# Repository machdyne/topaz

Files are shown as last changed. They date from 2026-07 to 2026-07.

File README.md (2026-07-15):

# Topaz Computer

Topaz is a headless computer that uses an ASIC module based on the open-source [KIAN-V RV32 SOC](https://github.com/splinedrive/gf180mcu-kianv-rv32ima-sv32).

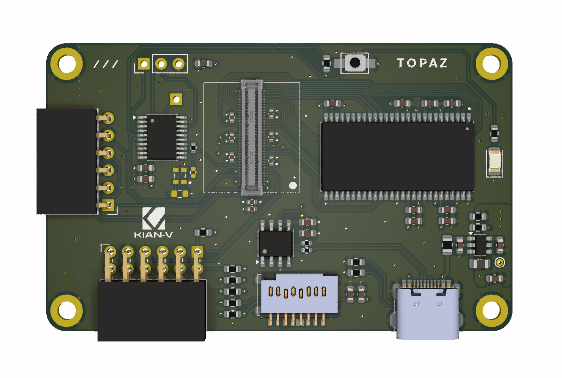
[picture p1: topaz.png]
Topaz Computer


This repo contains schematics, PCB layouts, firmware and documentation.

Find more information on the [Topaz product page](https://machdyne.com/product/topaz-computer/).

## License

The contents of this repo are released under the [Lone Dynamics Open License](LICENSE.md) with the following exceptions:

  * The ch32fun library is MIT licensed.

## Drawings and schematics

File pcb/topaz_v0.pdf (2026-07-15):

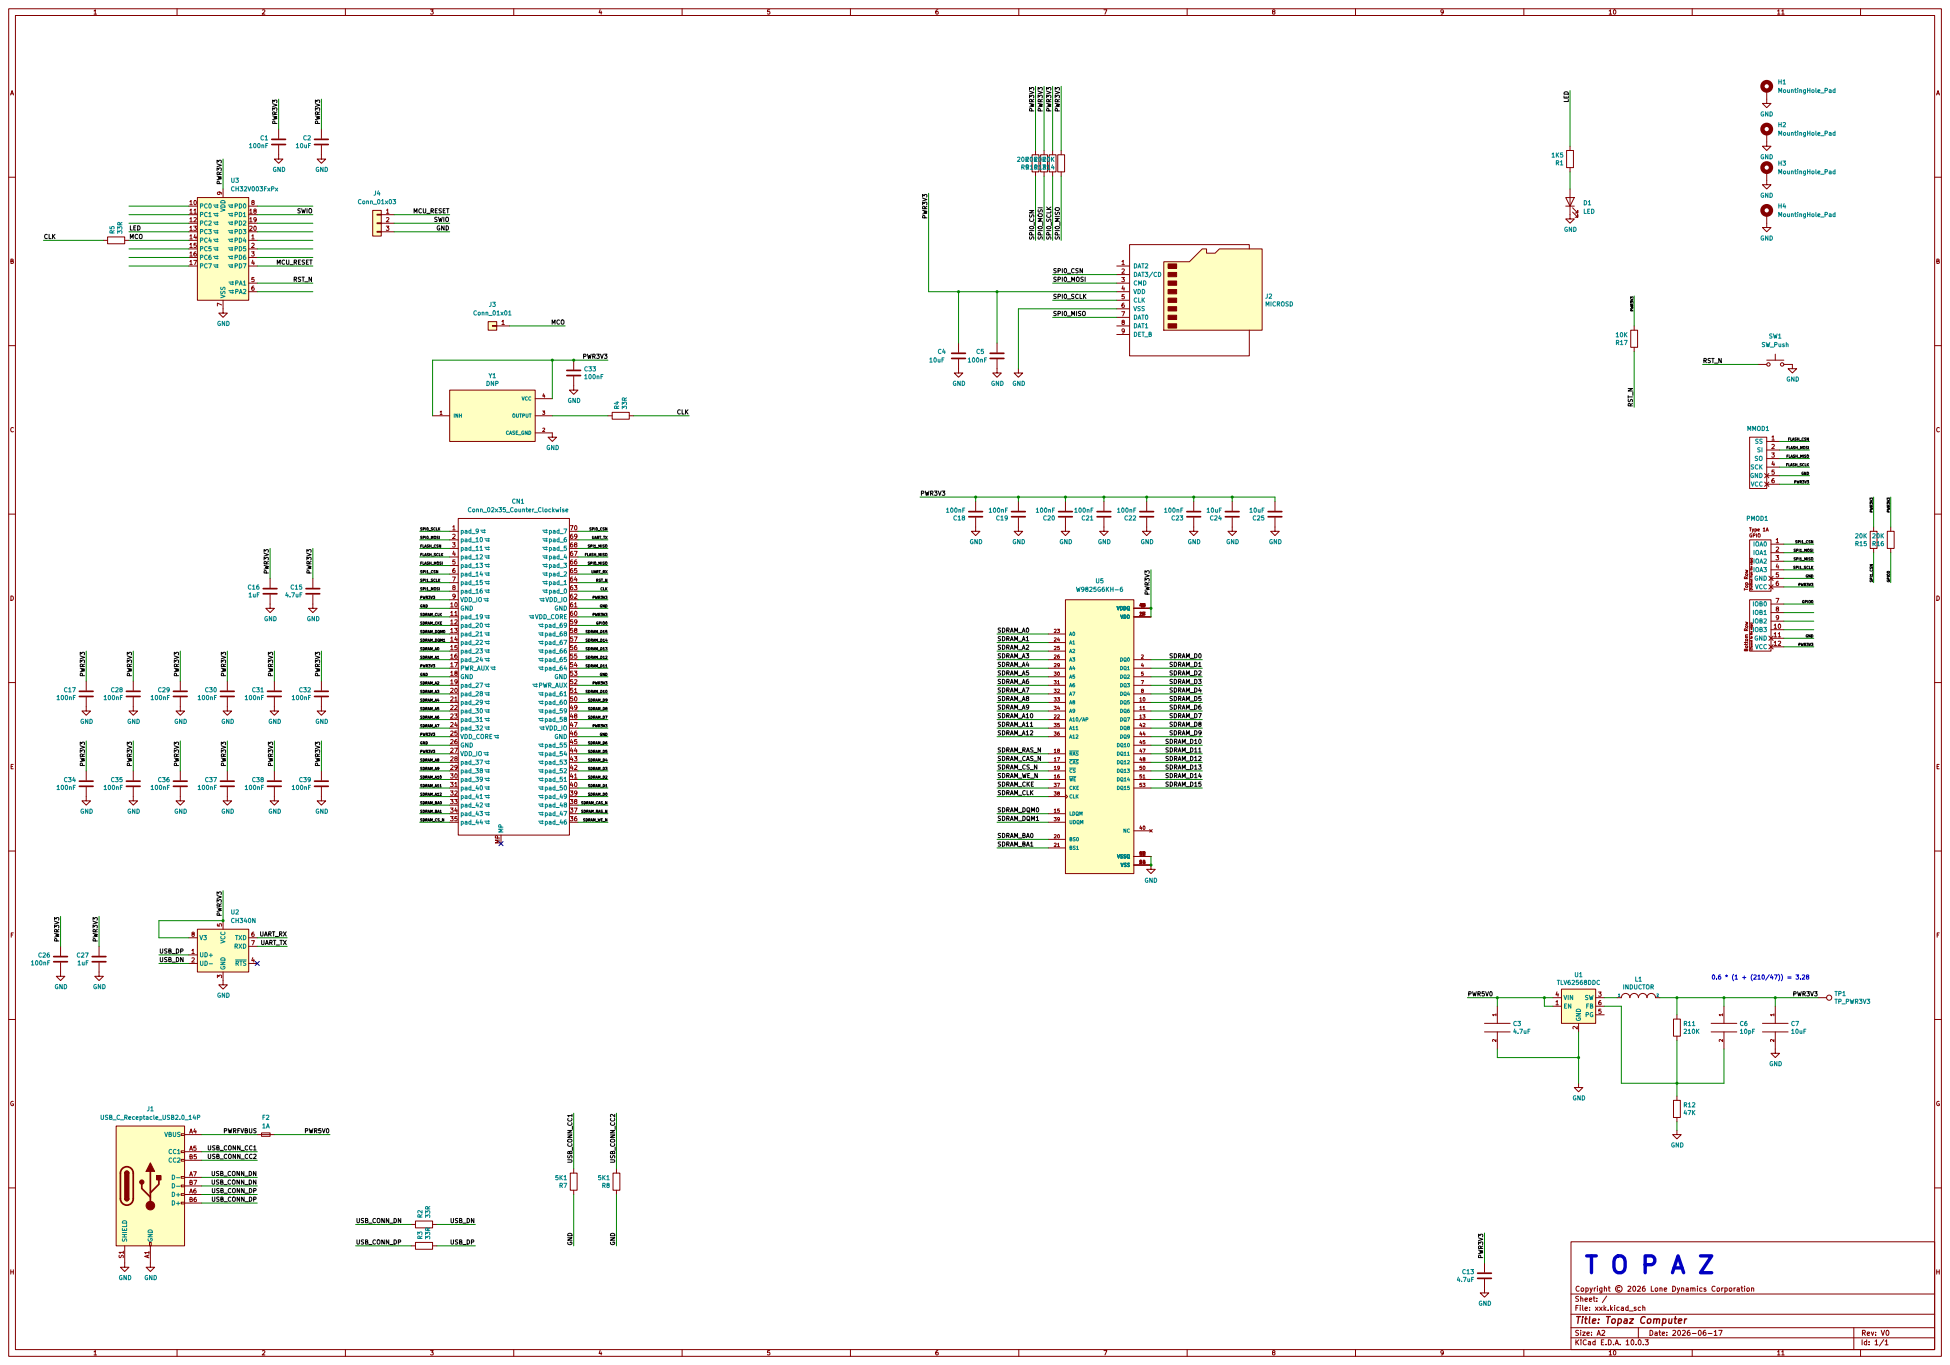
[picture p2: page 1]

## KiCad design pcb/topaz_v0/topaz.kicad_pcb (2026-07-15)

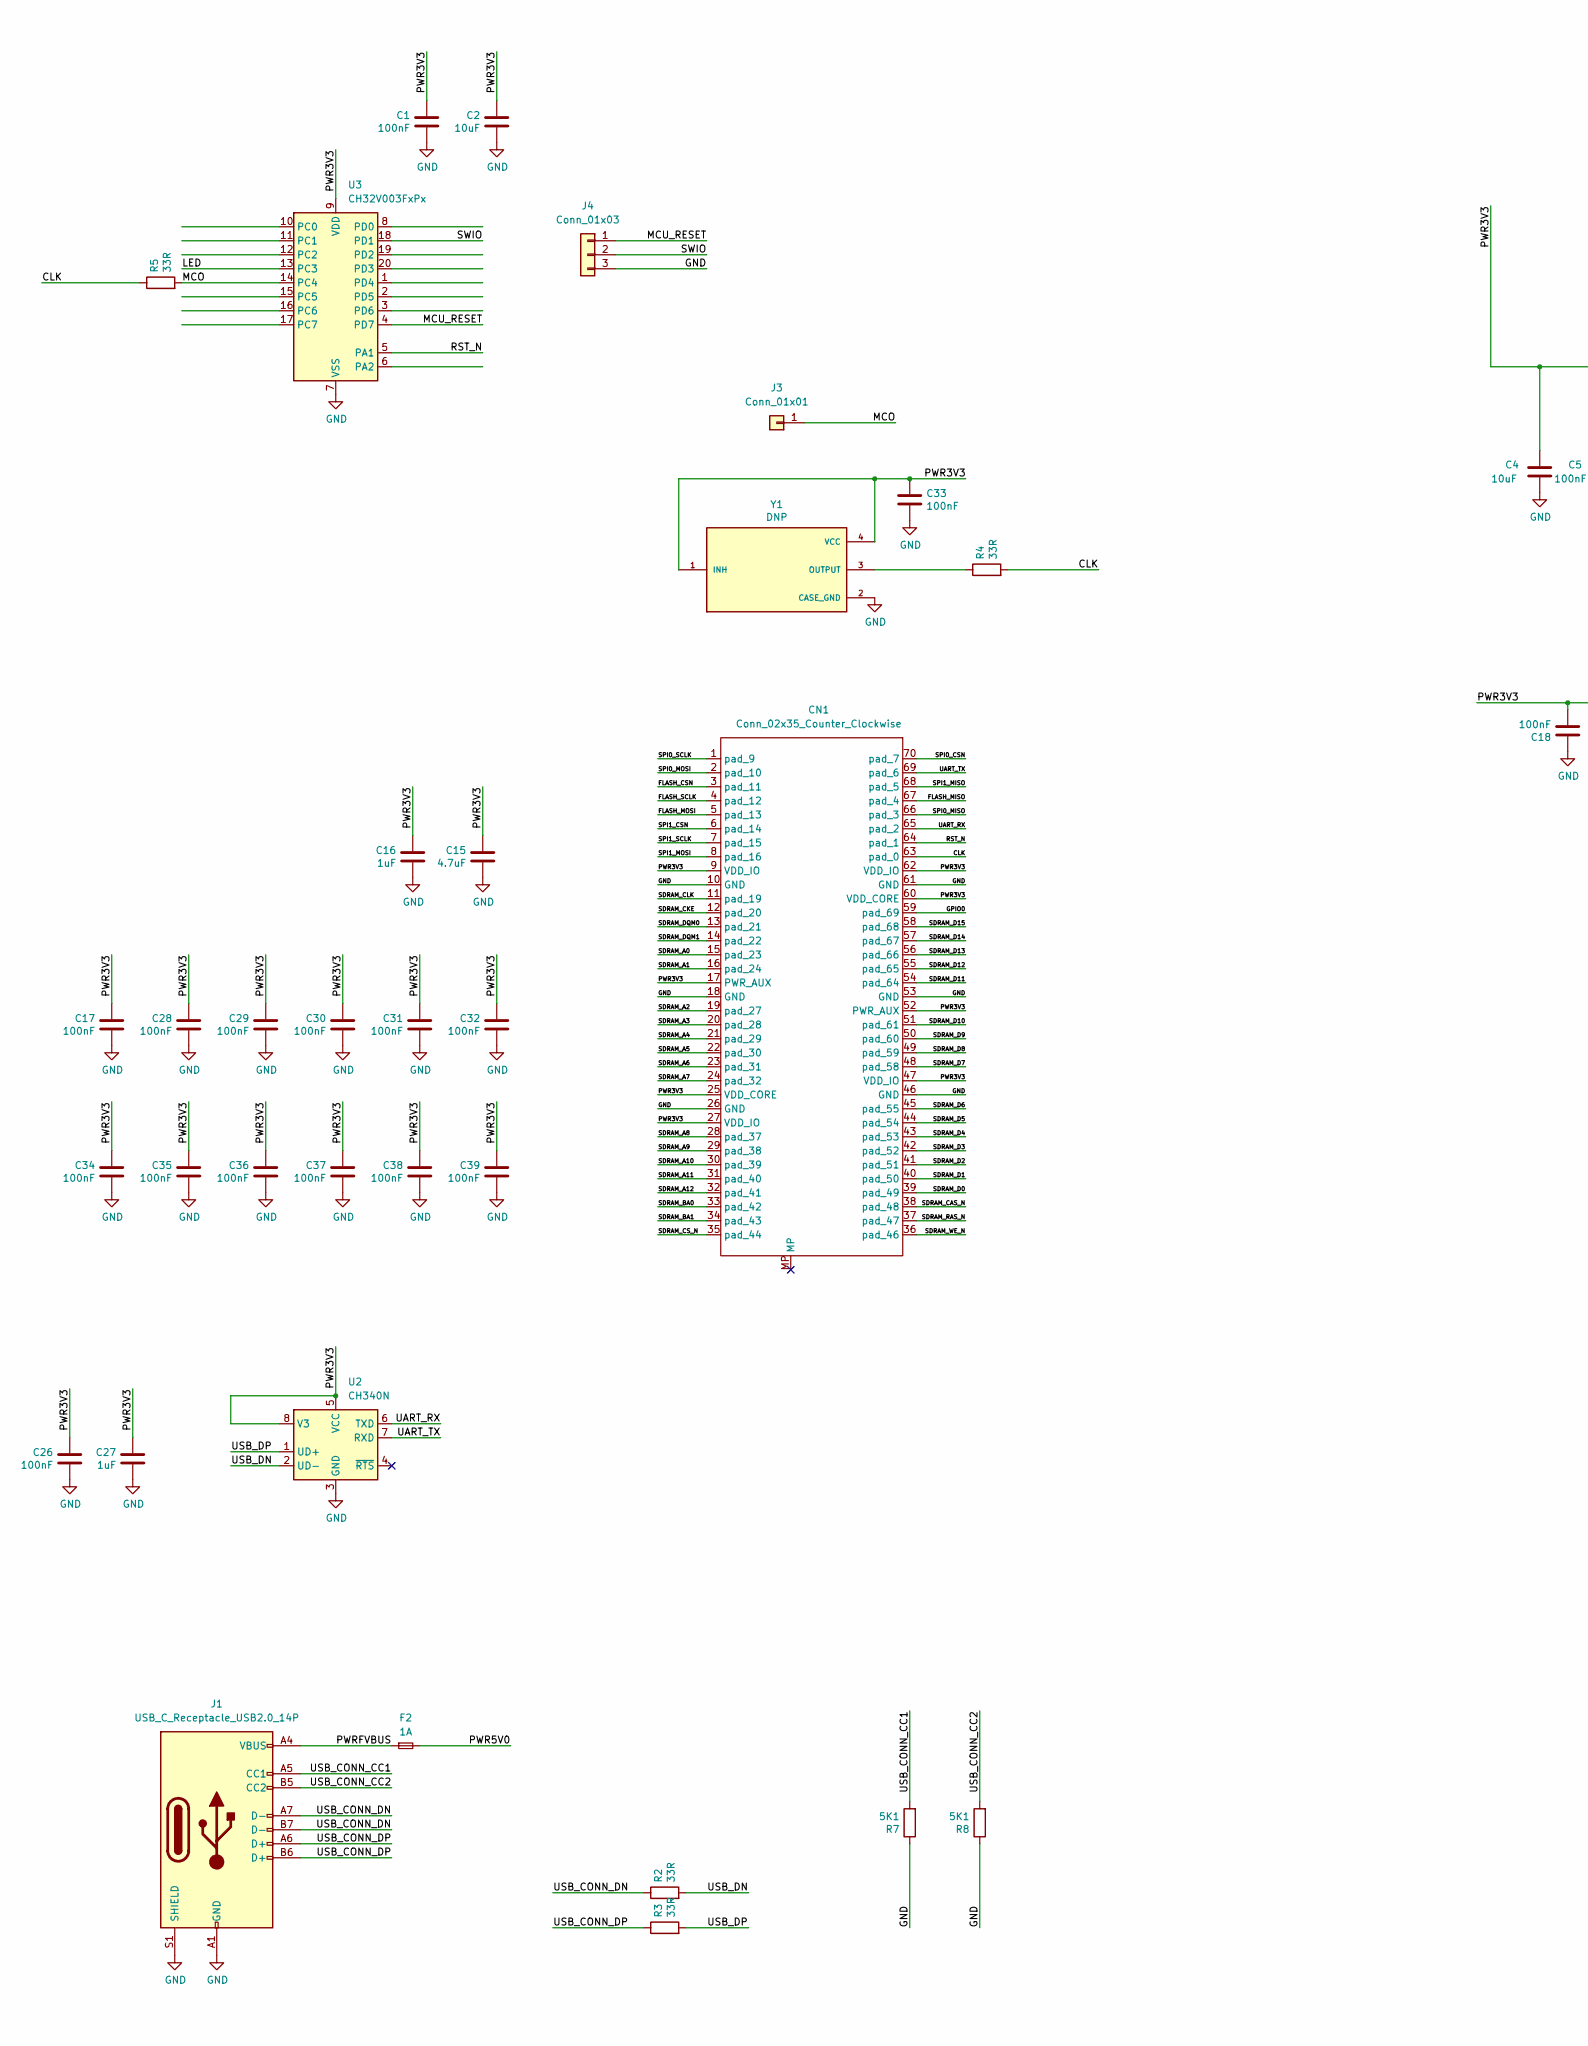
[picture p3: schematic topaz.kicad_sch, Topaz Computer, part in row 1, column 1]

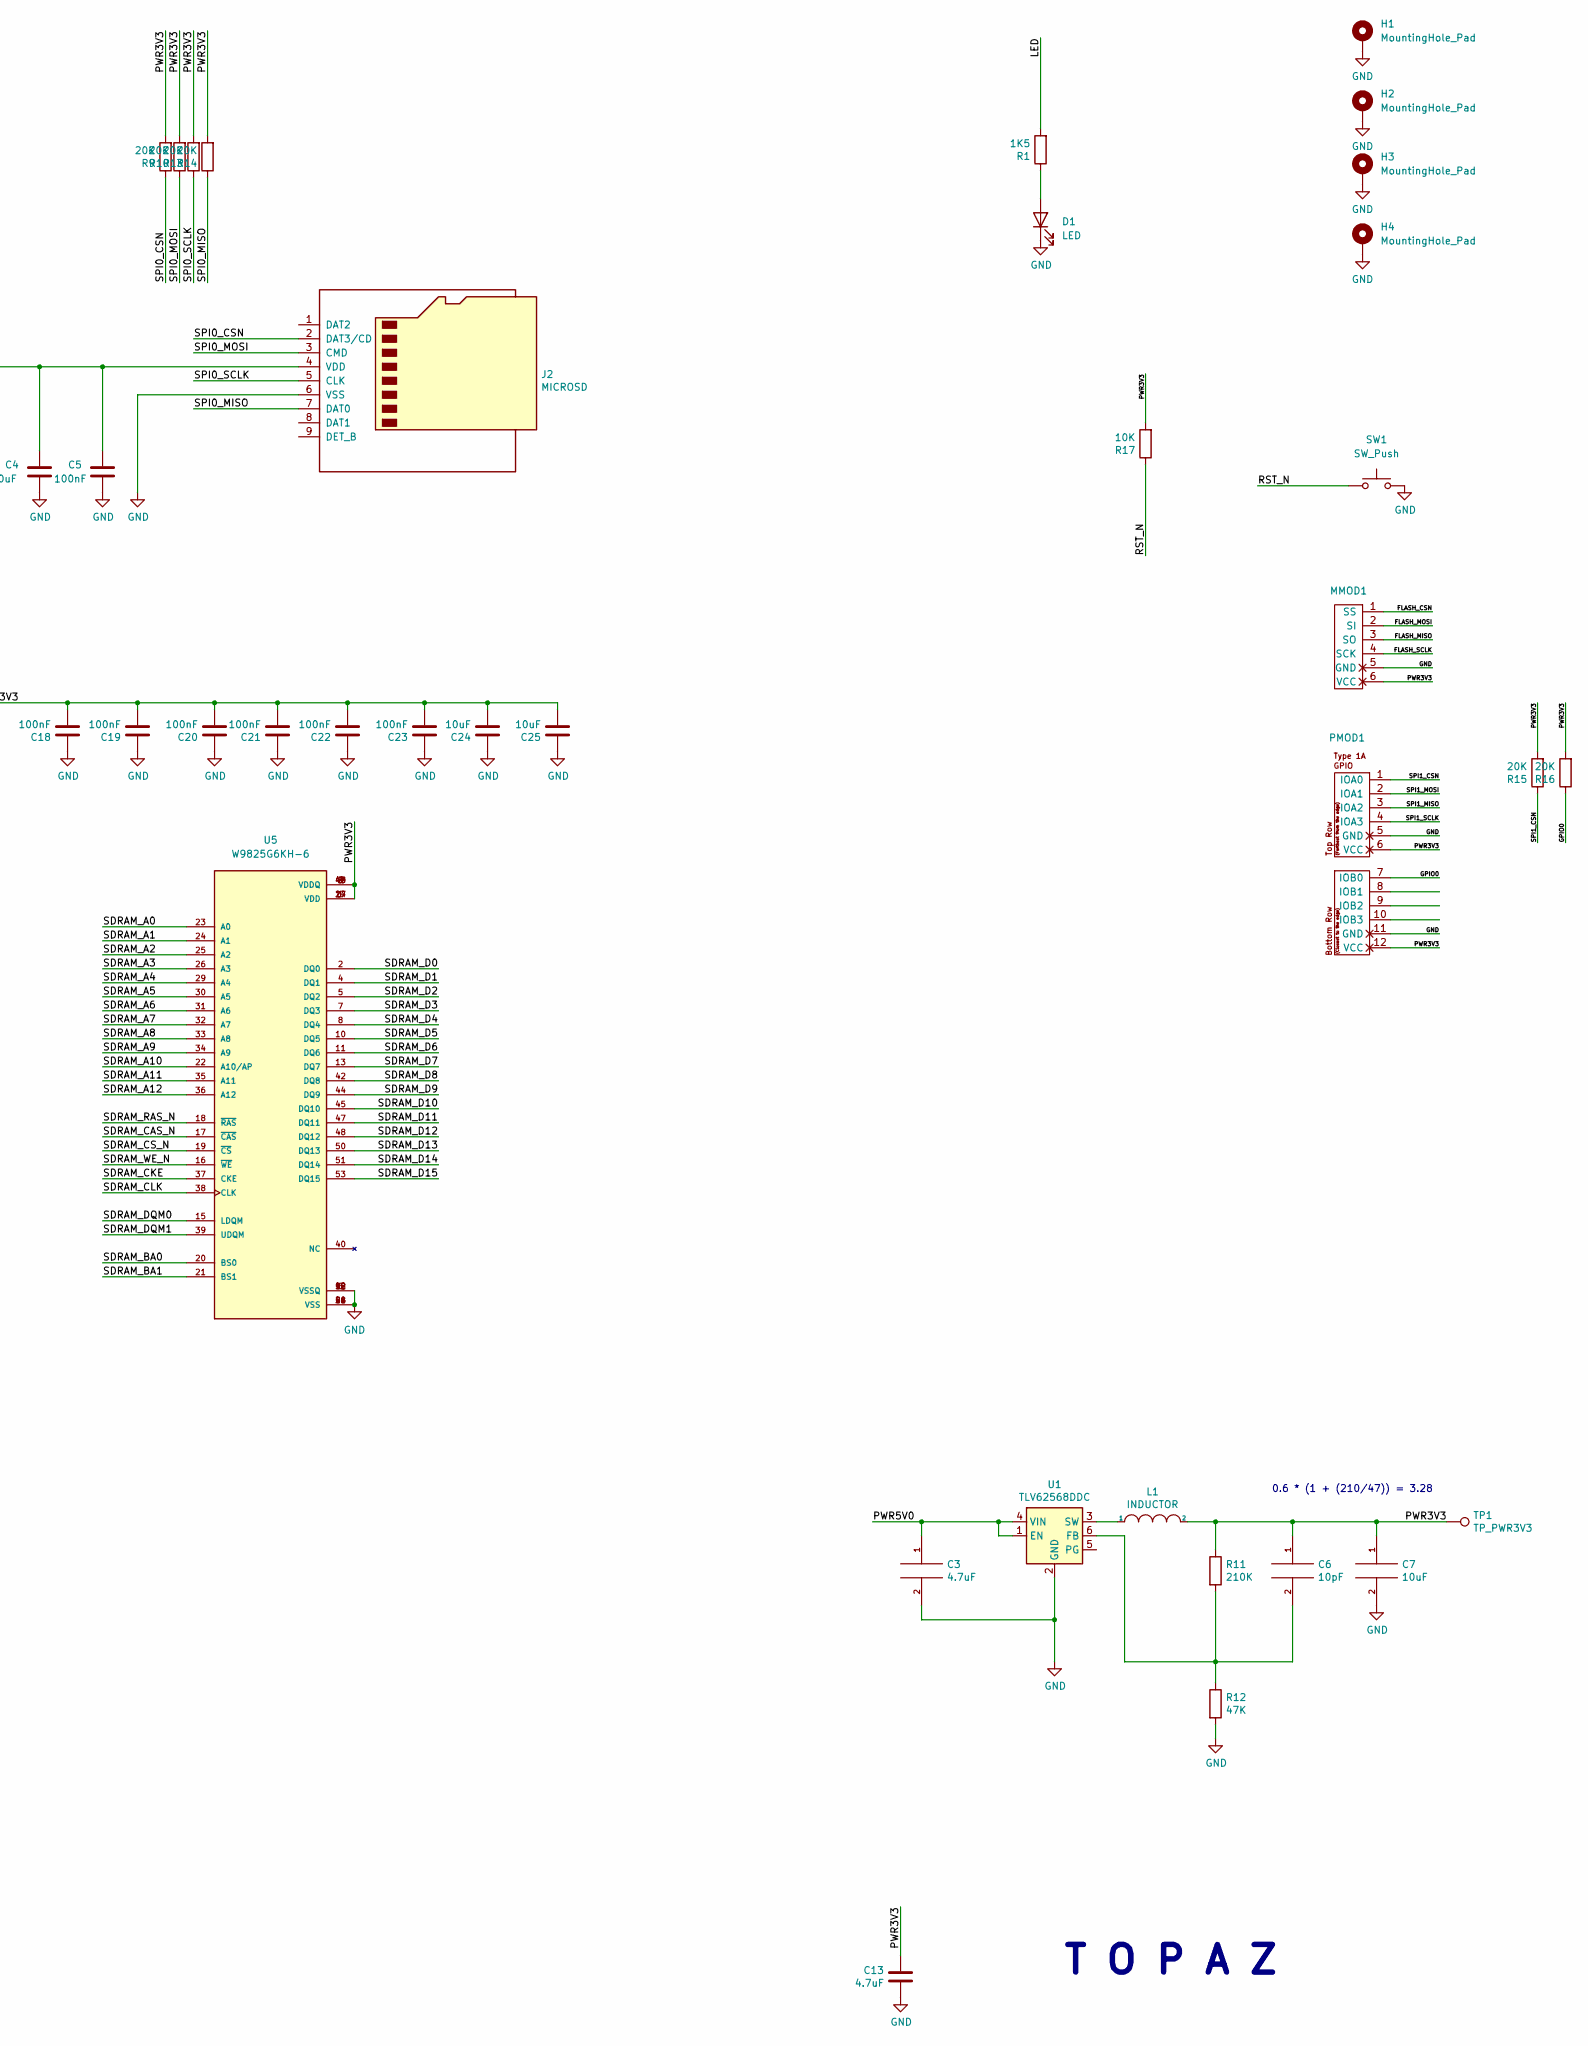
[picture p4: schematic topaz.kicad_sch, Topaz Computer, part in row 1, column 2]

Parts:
C1, C5, C18, C19, C20, C21, C22, C23, C26: 100nF; C_0603_1608Metric
C2, C4, C7, C24, C25: 10uF; C_0603_1608Metric
C3, C13: 4.7uF; C_0603_1608Metric
C6: 10pF; C_0603_1608Metric
C15: 4.7uF; C_0402_1005Metric
C16: 1uF; C_0402_1005Metric
C17, C28, C29, C30, C31, C32, C34, C35, C36, C37, C38, C39: 100nF; C_0402_1005Metric
C27: 1uF; C_0603_1608Metric
C33: 100nF; R_0603_1608Metric
CN1: Conn_02x35_Counter_Clockwise; CONN-SMD_70P-P0.40_HC-PBB40C-70DS-0.4V-3.0-02
D1: LED; LED_1206_3216Metric
F2: 1A; Fuse_0805_2012Metric
H1, H2, H3, H4: MountingHole_Pad; MountingHole_2.7mm_M2.5_DIN965_Pad
J1: USB_C_Receptacle_USB2.0_14P; USB_C_Receptacle_HRO_TYPE-C-31-M-12-BIG-PADS-PASTE
J2: MICROSD; TF-018B-H15-HAND-SOLDER
J3: Conn_01x01; PinHeader_1x01_P2.54mm_Vertical
J4: Conn_01x03; PinHeader_1x03_P2.54mm_Vertical
L1: INDUCTOR; L_0805_2012Metric
MMOD1: MMOD_Host_Socket
PMOD1: PMOD-Device-x2-Type-1A-GPIO; PMOD_2x06_HOST
R1: 1K5; R_0603_1608Metric
R2, R3, R4, R5: 33R; R_0402_1005Metric
R7, R8: 5K1; R_0603_1608Metric
R9, R10, R13, R14, R15, R16: 20K; R_0603_1608Metric
R11: 210K; R_0603_1608Metric
R12: 47K; R_0603_1608Metric
R17: 10K; R_0603_1608Metric
SW1: SW_Push; Button_2P_3x4mm
TP1: TP_PWR3V3; TestPoint_THTPad_D1.0mm_Drill0.5mm
U1: TLV62568DDC; SOT-23-6
U2: CH340N; SOP-8_3.9x4.9mm_P1.27mm
U3: CH32V003FxPx; TSSOP-20_4.4x6.5mm_P0.65mm
U5: W9825G6KH-6; SOP80P1176X120-54N; PARTREV A05
Y1: DNP; OSC_KC2016Z13.5600C1KX00; PARTREV November 2020

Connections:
/CLK: CN1.63 (pad_0), R4.2, R5.1
/FLASH_CSN: CN1.3 (pad_11), MMOD1.1 (SS)
/FLASH_MISO: CN1.67 (pad_4), MMOD1.3 (SO)
/FLASH_MOSI: CN1.5 (pad_13), MMOD1.2 (SI)
/FLASH_SCLK: CN1.4 (pad_12), MMOD1.4 (SCK)
/GPIO0: CN1.59 (pad_69), PMOD1.7 (IOB0), R16.1
/LED: R1.2, U3.13 (PC3)
/MCO: J3.1 (Pin_1_1), R5.2, U3.14 (PC4)
/MCU_RESET: J4.1, U3.4 (PD7)
/PWR3V3: C1.1, C2.1, C4.1, C5.1, C6.1, C7.1, C13.1, C15.1, C16.1, C17.1, C18.2, C19.2, C20.2, C21.2, C22.2, C23.2, C24.2, C25.2, C26.1, C27.1, C28.1, C29.1, C30.1, C31.1, C32.1, C33.1, C34.1, C35.1, C36.1, C37.1, C38.1, C39.1, CN1.9 (VDD_IO), CN1.17 (PWR_AUX), CN1.25 (VDD_CORE), CN1.27 (VDD_IO), CN1.47 (VDD_IO), CN1.52 (PWR_AUX), CN1.60 (VDD_CORE), CN1.62 (VDD_IO), J2.4 (VDD), L1.2, MMOD1.6 (VCC), PMOD1.6 (VCC), PMOD1.12 (VCC), R9.2, R10.2, R11.1, R13.2, R14.2, R15.2, R16.2, R17.2, TP1.1 (1_1), U2.5 (VCC), U2.8 (V3), U3.9 (VDD), U5.1 (VDD), U5.3 (VDDQ), U5.9 (VDDQ), U5.14 (VDD), U5.27 (VDD), U5.43 (VDDQ), U5.49 (VDDQ), Y1.1 (INH), Y1.4 (VCC)
/PWR5V0: C3.1, F2.2, U1.1 (EN), U1.4 (VIN)
/PWRFVBUS: F2.1, J1.A4 (VBUS), J1.A9 (VBUS), J1.B4 (VBUS), J1.B9 (VBUS)
/RST_N: CN1.64 (pad_1), R17.1, SW1.1, U3.5 (PA1)
/SDRAM_A0: CN1.15 (pad_23), U5.23 (A0)
/SDRAM_A1: CN1.16 (pad_24), U5.24 (A1)
/SDRAM_A2: CN1.19 (pad_27), U5.25 (A2)
/SDRAM_A3: CN1.20 (pad_28), U5.26 (A3)
/SDRAM_A4: CN1.21 (pad_29), U5.29 (A4)
/SDRAM_A5: CN1.22 (pad_30), U5.30 (A5)
/SDRAM_A6: CN1.23 (pad_31), U5.31 (A6)
/SDRAM_A7: CN1.24 (pad_32), U5.32 (A7)
/SDRAM_A8: CN1.28 (pad_37), U5.33 (A8)
/SDRAM_A9: CN1.29 (pad_38), U5.34 (A9)
/SDRAM_A10: CN1.30 (pad_39), U5.22 (A10/AP)
/SDRAM_A11: CN1.31 (pad_40), U5.35 (A11)
/SDRAM_A12: CN1.32 (pad_41), U5.36 (A12)
/SDRAM_BA0: CN1.33 (pad_42), U5.20 (BS0)
/SDRAM_BA1: CN1.34 (pad_43), U5.21 (BS1)
/SDRAM_CAS_N: CN1.38 (pad_48), U5.17 (~CAS)
/SDRAM_CKE: CN1.12 (pad_20), U5.37 (CKE)
/SDRAM_CLK: CN1.11 (pad_19), U5.38 (CLK)
/SDRAM_CS_N: CN1.35 (pad_44), U5.19 (~CS)
/SDRAM_D0: CN1.39 (pad_49), U5.2 (DQ0)
/SDRAM_D1: CN1.40 (pad_50), U5.4 (DQ1)
/SDRAM_D2: CN1.41 (pad_51), U5.5 (DQ2)
/SDRAM_D3: CN1.42 (pad_52), U5.7 (DQ3)
/SDRAM_D4: CN1.43 (pad_53), U5.8 (DQ4)
/SDRAM_D5: CN1.44 (pad_54), U5.10 (DQ5)
/SDRAM_D6: CN1.45 (pad_55), U5.11 (DQ6)
/SDRAM_D7: CN1.48 (pad_58), U5.13 (DQ7)
/SDRAM_D8: CN1.49 (pad_59), U5.42 (DQ8)
/SDRAM_D9: CN1.50 (pad_60), U5.44 (DQ9)
/SDRAM_D10: CN1.51 (pad_61), U5.45 (DQ10)
/SDRAM_D11: CN1.54 (pad_64), U5.47 (DQ11)
/SDRAM_D12: CN1.55 (pad_65), U5.48 (DQ12)
/SDRAM_D13: CN1.56 (pad_66), U5.50 (DQ13)
/SDRAM_D14: CN1.57 (pad_67), U5.51 (DQ14)
/SDRAM_D15: CN1.58 (pad_68), U5.53 (DQ15)
/SDRAM_DQM0: CN1.13 (pad_21), U5.15 (LDQM)
/SDRAM_DQM1: CN1.14 (pad_22), U5.39 (UDQM)
/SDRAM_RAS_N: CN1.37 (pad_47), U5.18 (~RAS)
/SDRAM_WE_N: CN1.36 (pad_46), U5.16 (~WE)
/SPI0_CSN: CN1.70 (pad_7), J2.2 (DAT3/CD), R9.1
/SPI0_MISO: CN1.66 (pad_3), J2.7 (DAT0), R14.1
/SPI0_MOSI: CN1.2 (pad_10), J2.3 (CMD), R10.1
/SPI0_SCLK: CN1.1 (pad_9), J2.5 (CLK), R13.1
/SPI1_CSN: CN1.6 (pad_14), PMOD1.1 (IOA0), R15.1
/SPI1_MISO: CN1.68 (pad_5), PMOD1.3 (IOA2)
/SPI1_MOSI: CN1.8 (pad_16), PMOD1.2 (IOA1)
/SPI1_SCLK: CN1.7 (pad_15), PMOD1.4 (IOA3)
/SWIO: J4.2, U3.18 (PD1)
/UART_RX: CN1.65 (pad_2), U2.6 (TXD)
/UART_TX: CN1.69 (pad_6), U2.7 (RXD)
/USB_CONN_CC1: J1.A5 (CC1), R7.2
/USB_CONN_CC2: J1.B5 (CC2), R8.2
/USB_CONN_DN: J1.A7 (D-), J1.B7 (D-), R2.1
/USB_CONN_DP: J1.A6 (D+), J1.B6 (D+), R3.1
/USB_DN: R2.2, U2.2 (UD-)
/USB_DP: R3.2, U2.1 (UD+)
GND: C1.2, C2.2, C3.2, C4.2, C5.2, C7.2, C13.2, C15.2, C16.2, C17.2, C18.1, C19.1, C20.1, C21.1, C22.1, C23.1, C24.1, C25.1, C26.2, C27.2, C28.2, C29.2, C30.2, C31.2, C32.2, C33.2, C34.2, C35.2, C36.2, C37.2, C38.2, C39.2, CN1.10 (GND), CN1.18 (GND), CN1.26 (GND), CN1.46 (GND), CN1.53 (GND), CN1.61 (GND), D1.1 (K), H1.1 (1_1), H2.1 (1_1), H3.1 (1_1), H4.1 (1_1), J1.A1 (GND), J1.A12 (GND), J1.B1 (GND), J1.B12 (GND), J1.S1 (SHIELD), J2.6 (VSS), J4.3, MMOD1.5 (GND), PMOD1.5 (GND), PMOD1.11 (GND), R7.1, R8.1, R12.2, SW1.2, U1.2 (GND), U2.3 (GND), U3.7 (VSS), U5.6 (VSSQ), U5.12 (VSSQ), U5.28 (VSS), U5.41 (VSS), U5.46 (VSSQ), U5.52 (VSSQ), U5.54 (VSS), Y1.2 (CASE_GND)
unnamed: D1.2 (A), R1.1
unnamed: C6.2, R11.2, R12.1, U1.6 (FB)
unnamed: L1.1, U1.3 (SW)
unnamed: R4.1, Y1.3 (OUTPUT)

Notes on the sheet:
T O P A Z
0.6 * (1 + (210/47)) = 3.28

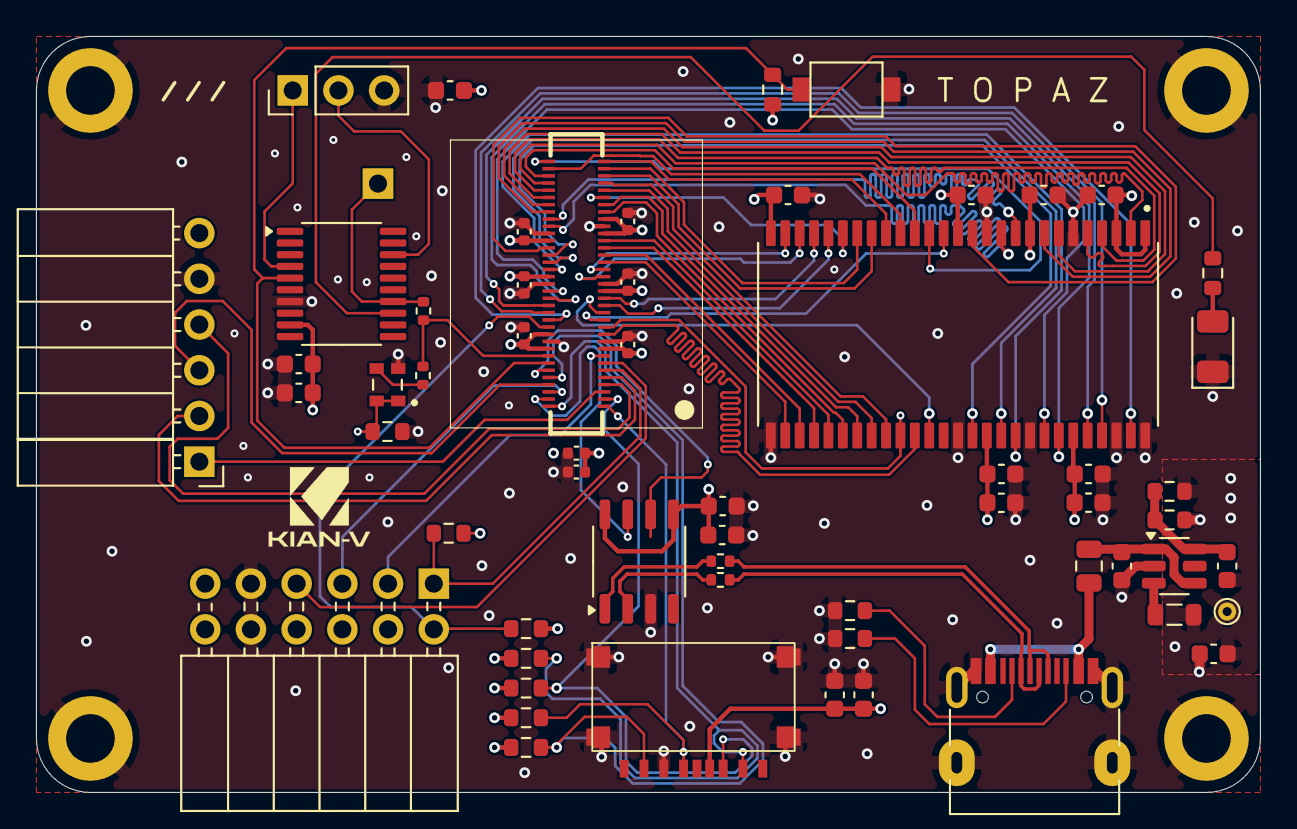
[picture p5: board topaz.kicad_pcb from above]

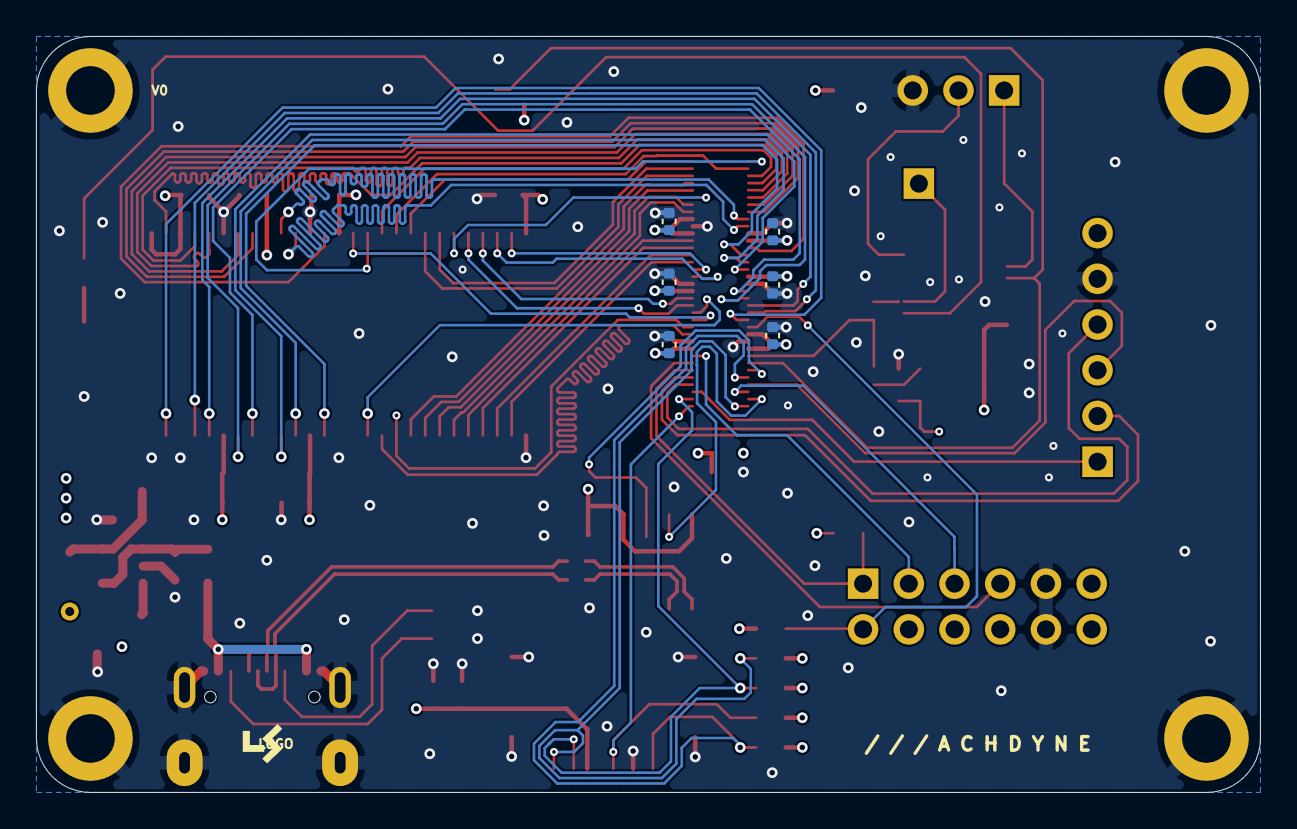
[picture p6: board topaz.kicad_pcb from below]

Board: 4 copper layers, 68.0 x 42.0 mm, 70 parts (6 on the bottom side), 74 nets.

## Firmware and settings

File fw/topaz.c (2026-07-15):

/*
 * Topaz Firmware
 *
 */

#include <stdio.h>
#include <string.h>
#include <stdint.h>
#include "ch32fun.h"

#define LED_PIN 3   /* PC3 */
#define MCO_PIN 4   /* PC4 */
#define RST_PIN 1   /* PA1 -> ASIC RST_N */

/* Select the MCO output frequency, in Hz. Change this one line.
 *
 *   0         -- PC4 driven high-Z (floating input); use this when an
 *                external clock source is supplied on PC4 instead
 *   24000000  -- native MCO peripheral, source = HSI
 *   48000000  -- native MCO peripheral, source = SYSCLK
 *
 * Only these three values are supported. All of them are a single native
 * MCO register write (or, for 0, just switching PC4 to an input) -- no
 * timer is ever involved, so the output is always a clean edge straight
 * from the MCO hardware, and TIM1 is always free for the LED.
 */
#ifndef MCO_FREQ_HZ
//#define MCO_FREQ_HZ 0
#define MCO_FREQ_HZ 24000000
#endif

/* How long to hold RST_N low before releasing it, after MCO is running */
#define RST_PULSE_MS 100

#if MCO_FREQ_HZ == 0
	#define MCO_MODE_EXTERNAL 1
#elif MCO_FREQ_HZ == 24000000
	#define MCO_MODE_NATIVE_HSI 1
#elif MCO_FREQ_HZ == 48000000
	#define MCO_MODE_NATIVE_SYSCLK 1
#else
	#error "MCO_FREQ_HZ must be 0, 24000000, or 48000000."
#endif

/* ── LED (PC3, TIM1 Channel 3 PWM, "breathing" fade) ──────────────────────
 *
 * PC3 is TIM1_CH3 in the default (no-remap) pin mapping. MCO never uses
 * TIM1 now (only the native SYSCLK/HSI mux, or high-Z), so TIM1 is always
 * free for the LED -- a full 256-step, ~3.9 kHz PWM every time, no
 * shared-timer caveats. Brightness follows volume^2 as volume ramps
 * 0..255..0, matching the eye's roughly power-law brightness perception
 * so the fade looks smooth rather than linear/robotic.
 */

#define LED_PWM_PERIOD 256UL

static void led_pwm_init(void)
{
    RCC->APB2PCENR |= RCC_APB2Periph_GPIOC | RCC_APB2Periph_TIM1;

    /* PC3 as TIM1_CH3 alternate function push-pull (default mapping) */
    GPIOC->CFGLR &= ~(0xFu << (4 * LED_PIN));
    GPIOC->CFGLR |=  (GPIO_CNF_OUT_PP_AF | GPIO_Speed_10MHz) << (4 * LED_PIN);

    /* CH3 output compare: PWM mode 1 (OC3M = 110) -- high while CNT < CCR */
    TIM1->CHCTLR2 &= ~(TIM_OC3M | TIM_CC3S);
    TIM1->CHCTLR2 |=  (TIM_OC3M_2 | TIM_OC3M_1);
    TIM1->CH3CVR   = 0;               /* start fully off */
    TIM1->CCER    |= TIM_CC3E;

    /* PSC=47 -> 48MHz/48 = 1MHz timer clock; ATRLR=255 -> ~3.9kHz PWM */
    TIM1->PSC     = 47;
    TIM1->ATRLR   = LED_PWM_PERIOD - 1;
    TIM1->SWEVGR |= TIM_UG;
    TIM1->CTLR1  |= TIM_CEN;
    TIM1->BDTR   |= TIM_MOE;

    printf("led_pwm_init: PC3=TIM1_CH3, PWM period=%lu counts\n",
           (unsigned long)LED_PWM_PERIOD);
}

/* Advance the breathing animation by one step. Call this periodically
 * (e.g. every ~8ms) from the main loop. */
static void led_breathe_step(void)
{
    static uint16_t volume = 0;
    static int8_t   dir = 1;

    uint32_t duty = ((uint32_t)volume * volume * LED_PWM_PERIOD) / (256UL * 256UL);
    TIM1->CH3CVR = duty;

    if (dir > 0) {
        if (volume >= 255) dir = -1; else volume++;
    } else {
        if (volume == 0)   dir = 1;  else volume--;
    }
}

/* ── ASIC reset (RST_N, PA1, active-low, push-pull) ───────────────────────
 *
 * NOTE: PA1/PA2 default to normal GPIO function (AFIO_PCFR1.PA1PA2_RM = 0
 * on reset), so no remap is needed here. If this board ever grows an HSE
 * crystal on PA1/PA2, that bit would need to stay cleared for this to work.
 */

static inline void rst_assert(void)  { GPIOA->BSHR = (1u << (16 + RST_PIN)); } /* drive low  */
static inline void rst_release(void) { GPIOA->BSHR = (1u << RST_PIN); }        /* drive high */

static void rst_init(void)
{
    RCC->APB2PCENR |= RCC_APB2Periph_GPIOA;

    /* Assert reset before the pin becomes an output, so there's no glitch */
    rst_assert();

    GPIOA->CFGLR &= ~(0xFu << (4 * RST_PIN));
    GPIOA->CFGLR |=  (GPIO_Speed_10MHz | GPIO_CNF_OUT_PP) << (4 * RST_PIN);

    printf("rst_init: GPIOA CFGLR=0x%08lx OUTDR=0x%08lx (RST_N should read 0/low)\n",
           (unsigned long)GPIOA->CFGLR, (unsigned long)GPIOA->OUTDR);
}

/* ── MCO (clock output on PC4) ────────────────────────────────────────────
 *
 * Native MCO peripheral only -- see the MCO_FREQ_HZ block above. Always a
 * single register write (or a GPIO mode change for the high-Z/external
 * case), never a timer.
 */

static void mco_init(void)
{
    RCC->APB2PCENR |= RCC_APB2Periph_GPIOC;

#if defined(MCO_MODE_EXTERNAL)

    /* External clock supplied on PC4 -- put the pin in floating input
     * (genuinely high-Z, no pull resistor) so the MCU doesn't drive it. */
    GPIOC->CFGLR &= ~(0xFu << (4 * MCO_PIN));
    GPIOC->CFGLR |=  (GPIO_CNF_IN_FLOATING) << (4 * MCO_PIN); /* MODE=00 (input) */

    printf("mco_init: MCO_FREQ_HZ=0 -> PC4 set to floating input (high-Z), "
           "expecting an external clock. GPIOC CFGLR=0x%08lx\n",
           (unsigned long)GPIOC->CFGLR);
    return;

#endif

    /* CNF=10 (mux push-pull output), MODE=11 (30 MHz max speed) */
    GPIOC->CFGLR &= ~(0xFu << (4 * MCO_PIN));
    GPIOC->CFGLR |=  (GPIO_CNF_OUT_PP_AF | GPIO_Speed_30MHz) << (4 * MCO_PIN);

#if defined(MCO_MODE_NATIVE_HSI)

    RCC->CFGR0 = (RCC->CFGR0 & ~RCC_CFGR0_MCO) | RCC_CFGR0_MCO_HSI;
    printf("mco_init: native HSI -> PC4, RCC CFGR0=0x%08lx\n", (unsigned long)RCC->CFGR0);

#elif defined(MCO_MODE_NATIVE_SYSCLK)

    RCC->CFGR0 = (RCC->CFGR0 & ~RCC_CFGR0_MCO) | RCC_CFGR0_MCO_SYSCLK;
    printf("mco_init: native SYSCLK -> PC4, RCC CFGR0=0x%08lx\n", (unsigned long)RCC->CFGR0);

#endif
}

/* ── Main ───────────────────────────────────────────────────────────────── */

int main(void)
{
	SystemInit();
	Delay_Ms(1);

	printf("\n--- Topaz boot ---\n");

	rst_init();     /* RST_N already held low from here */

	mco_init();     /* bring up the clock to the ASIC */
	led_pwm_init(); /* LED breathing PWM               */
	Delay_Ms(RST_PULSE_MS);

	rst_release();  /* let the ASIC come out of reset with a clock present */
	printf("rst_release: GPIOA OUTDR=0x%08lx (RST_N should read 1/high)\n",
	       (unsigned long)GPIOA->OUTDR);

	uint32_t heartbeat = 0;
	while (1) {
		led_breathe_step();
		Delay_Ms(8);
		if ((heartbeat % 128) == 0) {
			printf("heartbeat %lu\n", (unsigned long)(heartbeat / 128));
		}
		heartbeat++;
	}

}

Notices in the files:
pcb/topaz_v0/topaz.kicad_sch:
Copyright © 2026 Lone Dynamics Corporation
